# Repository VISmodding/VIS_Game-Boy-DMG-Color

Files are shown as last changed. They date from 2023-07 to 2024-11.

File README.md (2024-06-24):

# Game Boy DMG Color

Original MouseBiteLabs DMGC project can be found [here](https://github.com/MouseBiteLabs/Game-Boy-DMG-Color)

In the DMGC_VIS_variant folder [here](https://github.com/VISmodding/VIS_Game-Boy-DMG-Color/tree/main/DMGC_VIS_variant) you can find the VIS lipo battery variant of the origianl DMGC project.

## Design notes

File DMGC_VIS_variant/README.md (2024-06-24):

## Ensure to download the last version of the production files before production (v.4.0 for rev E and v4.1 for rev A, B, C or D).

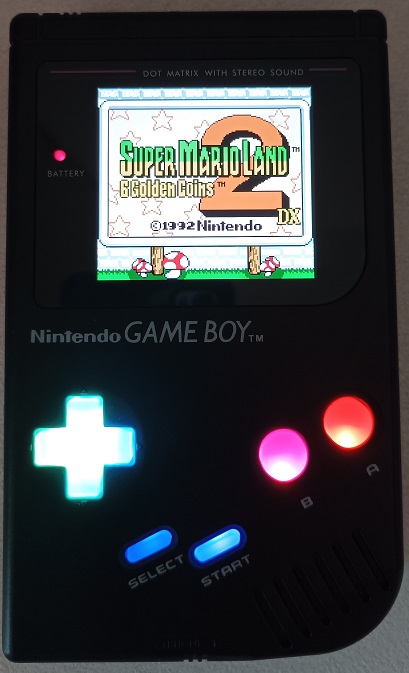
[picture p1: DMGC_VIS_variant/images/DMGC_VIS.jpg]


YouTube video [here](https://www.youtube.com/watch?v=p8AL-SyXEpo&t=13s&ab_channel=V1sModding).
Detailed PCB images can be seen in the production info section [here](PCB_info.md).

This is a modified version of the [MouseBitLab](https://github.com/MouseBiteLabs/Game-Boy-DMG-Color) DMGC project. The changes I have made are the following:
- The power board has been placed on the mainboard (it has a proper ground plane separated from the digital ground plane and from the audio ground plane) and it uses a Lipo battery (clearly it includes also the charger circuit).
- The audio board also has been modified in order to connect the speaker directly on it. For this reason the audio signals are not sent from the mainboard to the front board.
- The DMG donor is not required here (only the link port is needed and it can be sourced directly from the 4-player adapter DMG-07 which is cheap and can source 3 link ports).
- This DMGC VIS variant uses also a different DC jack since we need here of a jack capable to handle 2A current for the charger.
- I provide also the mainboard for the CPU-06 (rev E): the version of the CPU with the RAM already in CPU.

## Disclaimer

**This is a DIY project for electronic enthusiasts. For this reason, I am not responsible for any damage incurred while attempting this project or after completion of the project. You alone accept all risk since you are 100% liable for damage to yourself or your property.**

## Security information for Lipo Battery
The battery is physically distant form the tp4056 linear charger. In addition, the following features are implemented:
- Overcharge and overdischarge protections achieved through the widely used and widespread combo FS8205A - DW01A.
- Load sharing: you can safely play while charging the battery since the battery is disconnected from the load while charging (I use the same circuit of SYF Game Gear since its creator allowed me to use it). 

## Required Donor parts

In this project, the **strictly required donor parts** are only 
  - the **CPU** (that can be sourced from a donor CGB mainboard). For rev E version you need to grab also U11 component from the donor GBC.
  - the **link-port** (that can be sourced from a donor DMG mainboard or from a 4-player adapter DMG-07).

Other **optional components to desolder** from a donor console are:
  - **RAM** chip can be sourced from a donor CGB mainboard or it can be purchased (see BOM file).
  - **Card slot connector and volume wheel** can be sourced from a donor DMG mainboard or can be simply purchased on Aliexpress.
  - **Quartz oscillator** can be sourced from the donor GBC or it can be purchased (see BOM file).
  - **Power switch** can be sourced from a donor DMG mainboard, or a brand new switch can be purchased at any electronic components shop (see BOM file).

## Required Parts to purchase or reuse

  - **All the electronic components** reported in the BOM file.
  - **Housing DMG shell case** (optional if you already have one).
  - **Screen Kit** This is the important one. You need this specific type of kit
      - the Q5 IPS with OSD. It goes by many names, the maker is Hispeedido (*not* FunnyPlaying). Kits that have the screen laminated to a GBC lens are *not* compatible, but kits that include a lit-up logo on the bottom part of the screen are fine to use. Make sure you DO NOT get any Game Boy DMG versions - they are not compatible! Also, be sure to test this screen kit before installing it, preferrably with an original Game Boy Color. Sometimes they arrive damaged, and once you've installed, it may not be possible to get a refund.
      - RGRS: <a href="https://retrogamerepairshop.com/products/game-boy-color-q5-ips-backlight-with-osd?variant=37646279213228">GBC Q5 XL IPS Backlight with OSD</a> OR <a href="https://retrogamerepairshop.com/collections/gbc-displays/products/game-boy-color-q5-osd-ips-kit-with-color-changing-logo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">Game Boy Color Q5 OSD IPS Kit with Color Changing Logo 
      - AliExpress: <a href="https://www.aliexpress.us/item/3256801650459088.html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">GBC Q5 IPS LCD Kit</a>
      - HHL: <a href="https://handheldlegend.com/products/game-boy-color-ips-lcd-q5-hispeedido">Game Boy Color IPS LCD Q5 - Hispeedido</a>
  - **Lens:** You must get the "IPS" style of lens, as the viewing area is larger.
    -	RGRS: <a href="https://retrogamerepairshop.com/collections/dmg-lenses/products/funnyplaying-dmg-q5-ips-lens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">FunnyPlaying DMG Q5 IPS Lens</a>
    - FunnyPlaying: <a href="https://funnyplaying.com/products/dmg-retro-pixel-ips-glass-lens">DMG RetroPixel IPS Glass Lens</a>
  - **Screen Centering Bracket:** In the STL_3D_printer_files you can find:
    -  *dmgc_q5_bracket.stl*: it is the original bucket design (the screen is not covered by the bracket).
    -  *Vis_variant_LCD_bracket.stl*: it is a variant in which the screen is behind the bracket and in this case you need to apply hot glue to keep fix it.
  - **3.7V 125054 Lipo battery** (optional if you want to use only the DC jack).
  - **Kitsch-Bent full silicone buttons** (optional).
  - **1 Watt speaker** (optional if you want to use the original DMG speaker).  You can find (in the files of this project) the 3D model of the holder that you can use to take it in place without glue it to the housing shell (the holder fit the Retrosix 23 mm 1 watt speaker). If you buy 1 watt speaker please buy an high quality speaker from Retrosix (those that I use) or Handheldlegend avoiding cheap speakers.
  - **2 Watt speaker** (optional if you want to use the original DMG speaker). You can buy 28 mm of a very good quality here [Link Aliexpress](https://www.aliexpress.com/item/33037641624.html).
  - **wires and ph2.0 housing connectors** (optional) reported in the last sections of the BOM file.
  - **PH2.0 2.0mm Metal Crimp Pin Terminal Wire Cable for Housing PH 2.0 Female Socket Connector** (optional) that can be purchased here [Link Aliexpress](https://www.aliexpress.com/item/1005004266276874.html).
  - **5v 2A USB-C charger with the 2A cable USB adapter** (I suggest the right angle version) that can be purchased here [Link Aliexpress](https://www.aliexpress.com/item/4000285082506.html).
  - If you decide to use the **audio connector PCB** you can buy the 2.0 mm pitch headers from here [Link Aliexpress](https://www.aliexpress.com/item/4000694199194.html).
  - I suggest to use **full silicone buttons from Kitsch-Bent** as shown in this [short video](https://www.youtube.com/watch?v=DBGJTIemyE4&t=64s&ab_channel=V1sModding).
- I suggest to use **Kamicane USB-C Gasket** to refine the USB-C hole [3D model here](https://www.printables.com/it/model/217706-usb-type-c-gasket).

## Boards compatibility

  - Audio board is not compatible with exisisting gameboy boards and also with my previous Gameboy realeses.
  - MouseBiteLabs front IPS board can be used but in this case lines and ground planes are not kept separated. Anyway, the speaker must be connected in any case to the audio board.

## How produce the PCBs

link [here](PCB_info.md).

## How populate PCBs

Start by populating the power circuit shown in the following image.

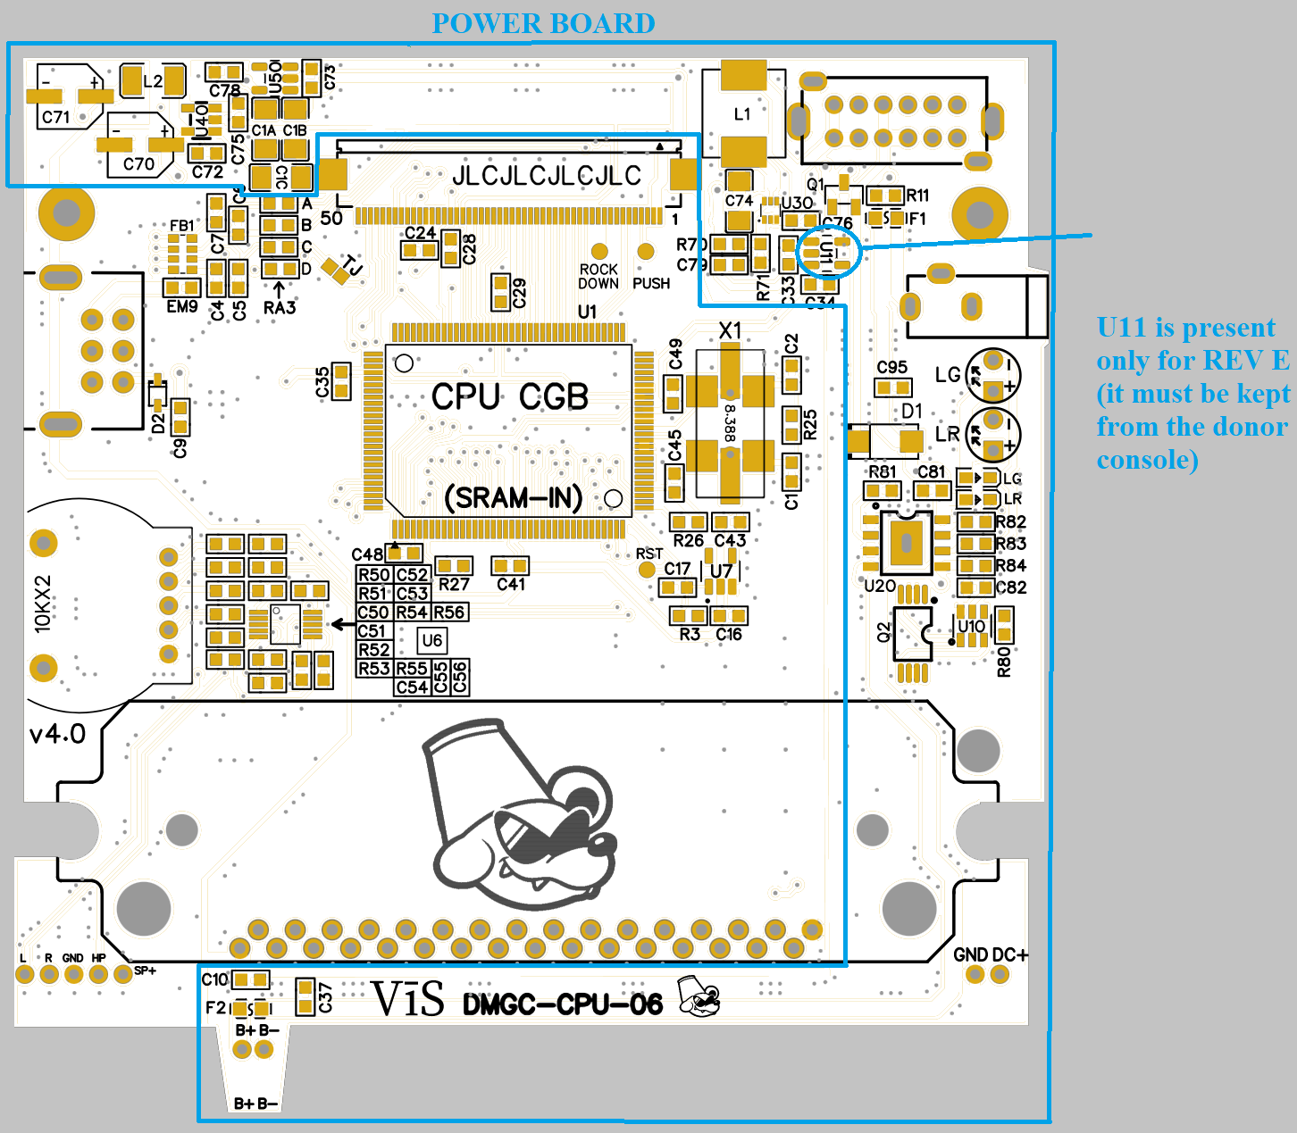
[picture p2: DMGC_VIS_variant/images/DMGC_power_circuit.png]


After that test the voltages on the back by using the pads highlighted in the following image ("Additional CPU lines voltage" pad is present only for the REV E. Here you should get something between 1.8 - 2.5 V) and test also the Lipo charger.

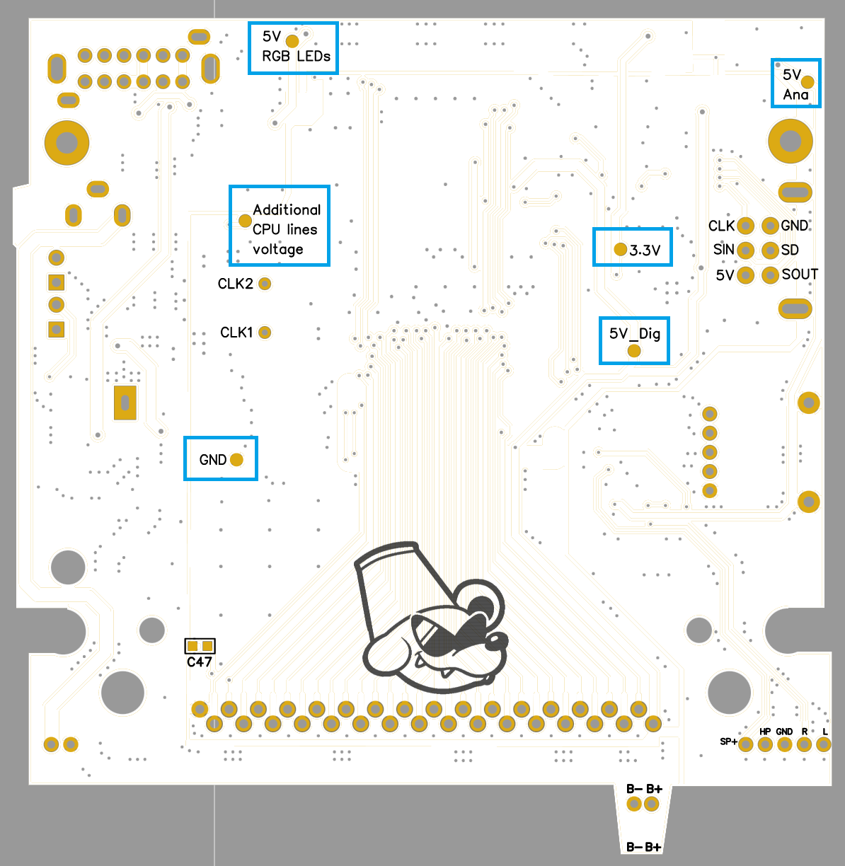
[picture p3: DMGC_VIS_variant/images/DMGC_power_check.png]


At this point you can finish to populate all the PCBs similarly to the MouseBitLabs DMGC. For the audio/USB-C connector please referr to the final part of the DMG v2 video [link](https://www.youtube.com/watch?v=zv3Ng8fEEQI&t=5s&ab_channel=V1sModding).

Finally, all the 7 mm tatcile switches have the same orientation. Referr to the following image for the orientation.

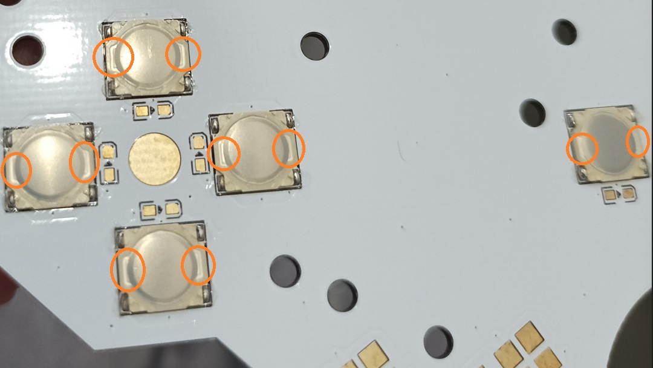
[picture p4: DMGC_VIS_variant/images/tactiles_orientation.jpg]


Other details can be found on the YouTube video [here](https://www.youtube.com/watch?v=p8AL-SyXEpo&t=13s&ab_channel=V1sModding).

## Credits

  - [Bucket Mouse](https://github.com/MouseBiteLabs/) for the [DMGC](https://github.com/MouseBiteLabs/Game-Boy-DMG-Color) project from which I started for this variant.

  - [consolesandcasks or Deceptive thinker](https://github.com/consolesandcasks) for another [Heavy CPU MGB](https://github.com/ConsolesandCasks/CPU-MGB-Heavy) project that I referenced and utilized to update the actual DC Jack.

  - [Kamicane](https://github.com/kamicane/) for the [Super DMG](https://github.com/kamicane/Super-DMG-01) project from wich I get the audio board shape.

  - [Reverse Retro Engineering](https://linktr.ee/reverseretro) for the help in design the rev E CPU.

## Acknowledgements

I would like to thank Mathijs (the creator of SYF Game Gear PCBs) for his several suggestions, schematics, and help in this project. I would like to thank also Luke from Retrosix for some usefull suggestions.

## License
<br />This work is licensed under a <a rel="license" href="http://creativecommons.org/licenses/by-sa/4.0/">Creative Commons Attribution-ShareAlike 4.0 International License</a>. You are able to copy and redistribute the material in any medium or format, as well as remix, transform, or build upon the material for any purpose (even commercial) - but you **must** give appropriate credit, provide a link to the license, and indicate if any changes were made.

## Support VIS projects

I have several stuffs in mind, and I will also share my normal Gameboy DMG work [YouTube Channel](https://www.youtube.com/channel/UC17bQxOnCBejYQG4rzEg3jA), but since developing these things has a high cost in materials and prototypes, a little [PayPal](https://www.paypal.com/donate/?hosted_button_id=RJM3TVFW38ZXL) donation is appreciated.

## Contacts

**email**: vis.modding@gmail.com <br />

**discord**: you can find me as *vis_modding* on several servers (BennVenn, Mouse Bit Lab, Retrosix modding, Game Boy, Gameboy makers, Cybdyn Systems, Pixel FX Official Discord, Modded Gameboy Club).

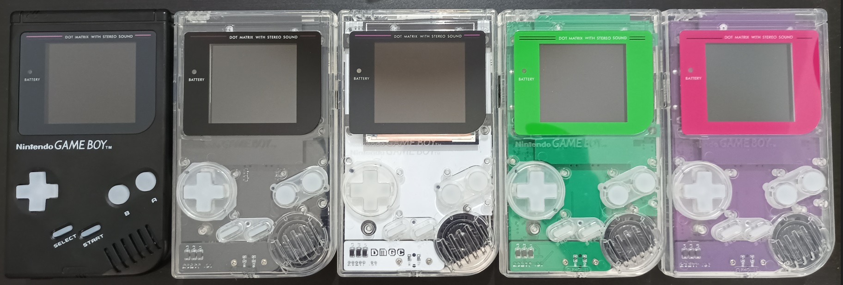
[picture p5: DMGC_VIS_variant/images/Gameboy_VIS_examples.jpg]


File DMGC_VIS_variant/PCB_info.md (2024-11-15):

# Production information

Gerber files are located inside ProductionFiles folder in which you can find 1 PCB in each file.
I suggest ENIG surface finish for easier soldering job and longer PCB shelf life.
Finally, all the PCBs are marked with the string "JLCJLCJLCJLC" in a position that will be covered by components or that will not be visible with the assembled Gameboy. If you order from JLCPCB, you can specify the location of the production file through this string, and they will replace "JLCJLCJLCJLC" with the production number in this location.
If you requires PCBs with a different string (to set the production number in the same location but using another service of production) send me an email and I will provide the modified Gerber files for your needs.
In the following screenshot you find the way to do this.

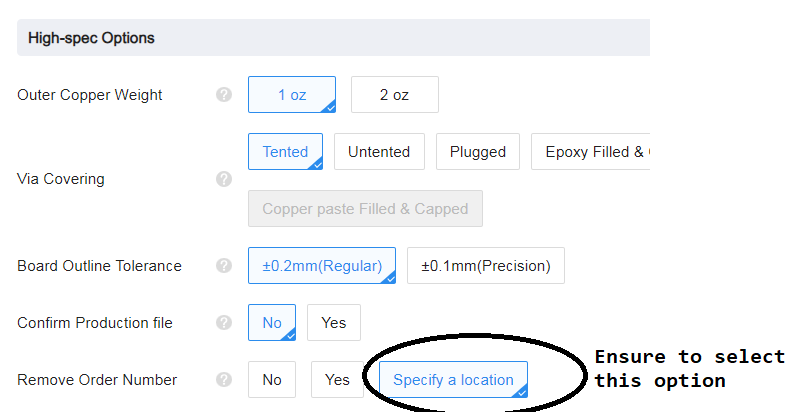
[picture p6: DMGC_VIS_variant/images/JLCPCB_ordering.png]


## Mainboard PCB (2 layers PCB)

Produce the mainboard PCB with 1 mm or 1.2 mm thickness. Here you have the CPU+RAM version or the RAM-IN-CPU (rev E) version.

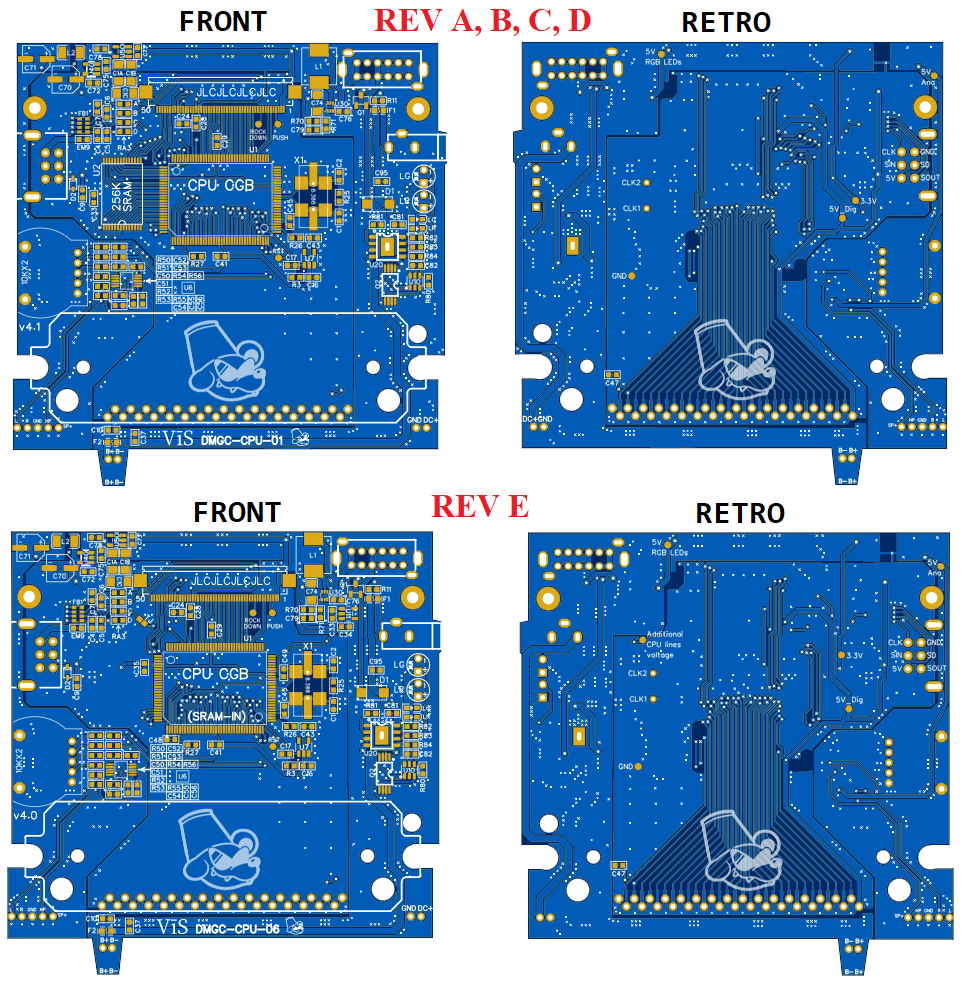
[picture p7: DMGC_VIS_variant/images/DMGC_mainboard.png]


## Audio PCB (2 layers PCB)

Produce the audio PCB with 1 mm or 1.2 mm thickness. 

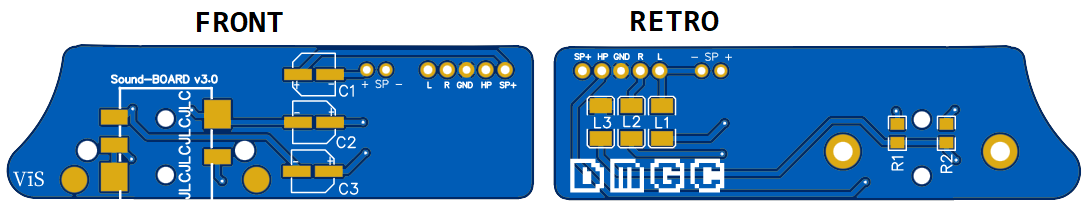
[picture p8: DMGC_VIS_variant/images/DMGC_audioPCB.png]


## Audio Jack raiser (2 layers PCB)

Produce Audio Jack raiser PCB with 1.6 mm thickness. If producer contact you by telling that PCB can break you answer to accept this risk and move on the production.

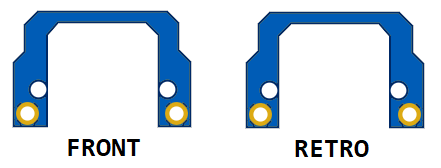
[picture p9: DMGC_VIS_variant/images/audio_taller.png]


## IPS front PCB (2 layers PCB)

Produce the IPS front PCB with 1 mm or 1.2 mm thickness (I suggest ENIG surface finish for better buttons feeling if you don't use tactile buttons). 
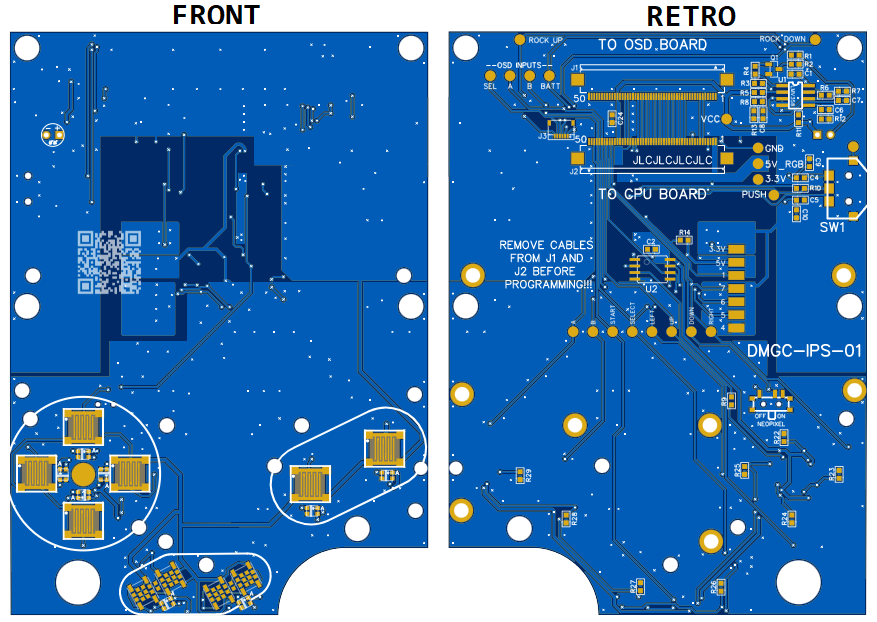
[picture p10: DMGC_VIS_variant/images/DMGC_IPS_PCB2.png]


## Audio connector PCB (2 layers PCB)

Produce the Audio connector PCB with 1 mm or less thickness.

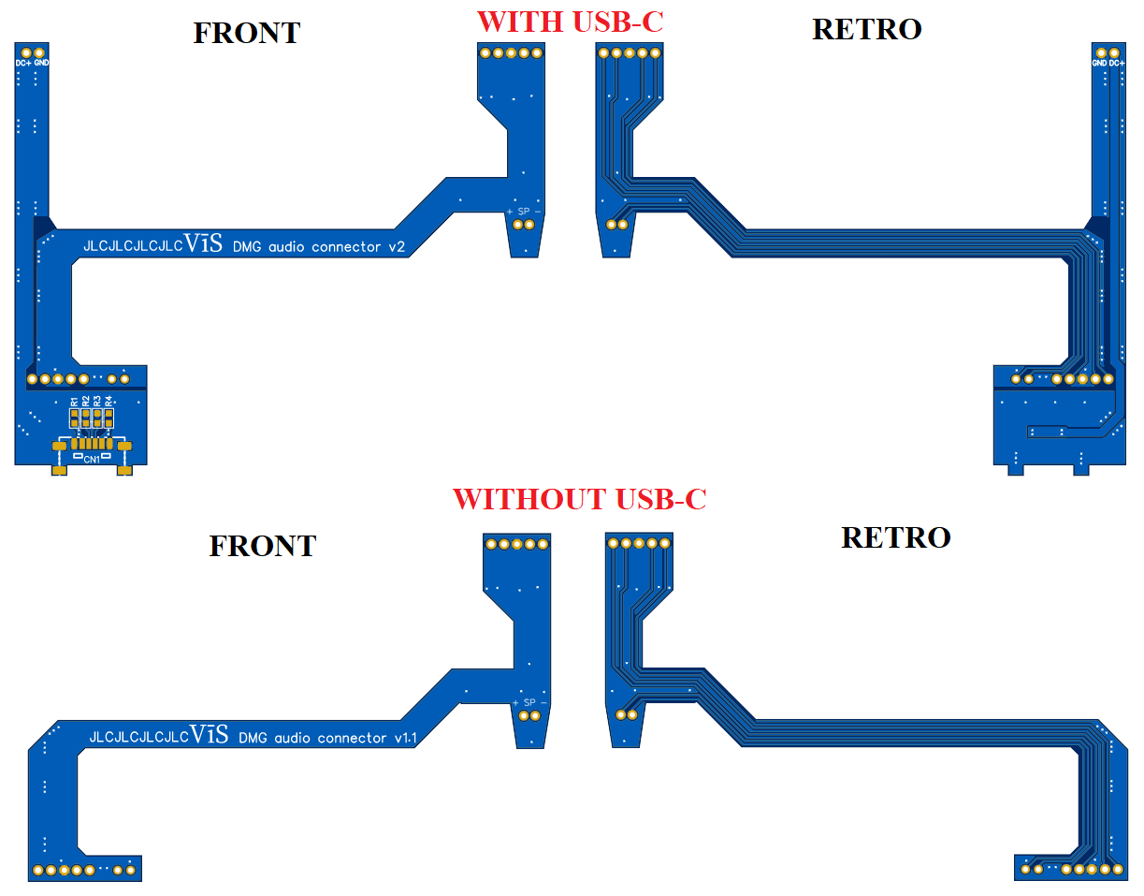
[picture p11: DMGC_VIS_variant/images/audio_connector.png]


## IPS OSD connector PCB (2 layers PCB)

Produce the IPS OSD connector PCB with 0.8 mm or less thickness.

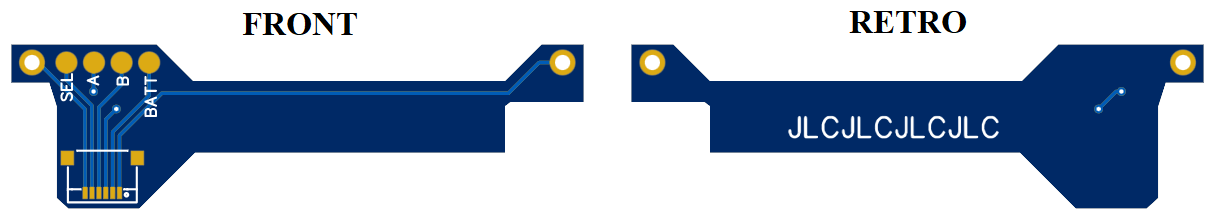
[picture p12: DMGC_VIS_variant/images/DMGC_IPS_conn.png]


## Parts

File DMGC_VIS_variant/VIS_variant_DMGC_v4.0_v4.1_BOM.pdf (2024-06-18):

# VIS GAMEBOY DMGC v4.0_v4.1 BOM

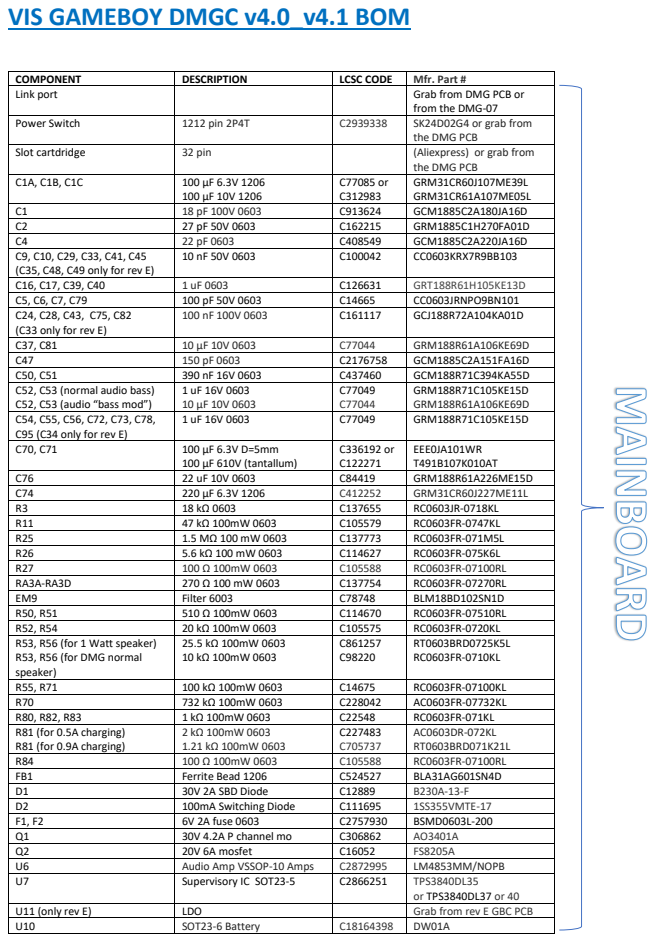
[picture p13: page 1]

COMPONENT | DESCRIPTION | LCSC CODE | Mfr. Part #
Link port | | | Grab from DMG PCB or from the DMG-07

Power Switch | 1212 pin 2P4T | C2939338 | SK24D02G4 or grab from the DMG PCB

Slot cartdridge | 32 pin | | (Aliexpress) or grab from the DMG PCB

C1A, C1B, C1C | 100 μF 6.3V 1206 100 μF 10V 1206 | C77085 or C312983 | GRM31CR60J107ME39L GRM31CR61A107ME05L

C1 | 18 pF 100V 0603 | C913624 | GCM1885C2A180JA16D
C2 | 27 pF 50V 0603 | C162215 | GRM1885C1H270FA01D
C4 | 22 pF 0603 | C408549 | GCM1885C2A220JA16D
C9, C10, C29, C33, C41, C45 (C35, C48, C49 only for rev E) | 10 nF 50V 0603 | C100042 | CC0603KRX7R9BB103

C16, C17, C39, C40 | 1 uF 0603 | C126631 | GRT188R61H105KE13D
C5, C6, C7, C79 | 100 pF 50V 0603 | C14665 | CC0603JRNPO9BN101
C24, C28, C43, C75, C82 (C33 only for rev E) | 100 nF 100V 0603 | C161117 | GCJ188R72A104KA01D

C37, C81 | 10 μF 10V 0603 | C77044 | GRM188R61A106KE69D
C47 | 150 pF 0603 | C2176758 | GCM1885C2A151FA16D
C50, C51 | 390 nF 16V 0603 | C437460 | GCM188R71C394KA55D
C52, C53 (normal audio bass) C52, C53 (audio “bass mod”) | 1 uF 16V 0603 10 μF 10V 0603 | C77049 C77044 | GRM188R71C105KE15D GRM188R61A106KE69D

C54, C55, C56, C72, C73, C78, C95 (C34 only for rev E) | 1 uF 16V 0603 | C77049 | GRM188R71C105KE15D

C70, C71 | 100 μF 6.3V D=5mm 100 μF 610V (tantallum) | C336192 or C122271 | EEE0JA101WR T491B107K010AT

C76 | 22 uF 10V 0603 | C84419 | GRM188R61A226ME15D
C74 | 220 μF 6.3V 1206 | C412252 | GRM31CR60J227ME11L
R3 | 18 kΩ 0603 | C137655 | RC0603JR-0718KL
R11 | 47 kΩ 100mW 0603 | C105579 | RC0603FR-0747KL
R25 | 1.5 MΩ 100 mW 0603 | C137773 | RC0603FR-071M5L
R26 | 5.6 kΩ 100 mW 0603 | C114627 | RC0603FR-075K6L
R27 | 100 Ω 100mW 0603 | C105588 | RC0603FR-07100RL
RA3A-RA3D | 270 Ω 100 mW 0603 | C137754 | RC0603FR-07270RL
EM9 | Filter 6003 | C78748 | BLM18BD102SN1D
R50, R51 | 510 Ω 100mW 0603 | C114670 | RC0603FR-07510RL
R52, R54 | 20 kΩ 100mW 0603 | C105575 | RC0603FR-0720KL
R53, R56 (for 1 Watt speaker) R53, R56 (for DMG normal speaker) | 25.5 kΩ 100mW 0603 10 kΩ 100mW 0603 | C861257 C98220 | RT0603BRD0725K5L RC0603FR-0710KL

R55, R71 | 100 kΩ 100mW 0603 | C14675 | RC0603FR-07100KL
R70 | 732 kΩ 100mW 0603 | C228042 | AC0603FR-07732KL
R80, R82, R83 | 1 kΩ 100mW 0603 | C22548 | RC0603FR-071KL
R81 (for 0.5A charging) R81 (for 0.9A charging) | 2 kΩ 100mW 0603 1.21 kΩ 100mW 0603 | C227483 C705737 | AC0603DR-072KL RT0603BRD071K21L

R84 | 100 Ω 100mW 0603 | C105588 | RC0603FR-07100RL
FB1 | Ferrite Bead 1206 | C524527 | BLA31AG601SN4D
D1 | 30V 2A SBD Diode | C12889 | B230A-13-F
D2 | 100mA Switching Diode | C111695 | 1SS355VMTE-17
F1, F2 | 6V 2A fuse 0603 | C2757930 | BSMD0603L-200
Q1 | 30V 4.2A P channel mo | C306862 | AO3401A
Q2 | 20V 6A mosfet | C16052 | FS8205A
U6 | Audio Amp VSSOP-10 Amps | C2872995 | LM4853MM/NOPB
U7 | Supervisory IC SOT23-5 | C2866251 | TPS3840DL35 or TPS3840DL37 or 40

U11 (only rev E) | LDO | | Grab from rev E GBC PCB
U10 | SOT23-6 Battery | C18164398 | DW01A

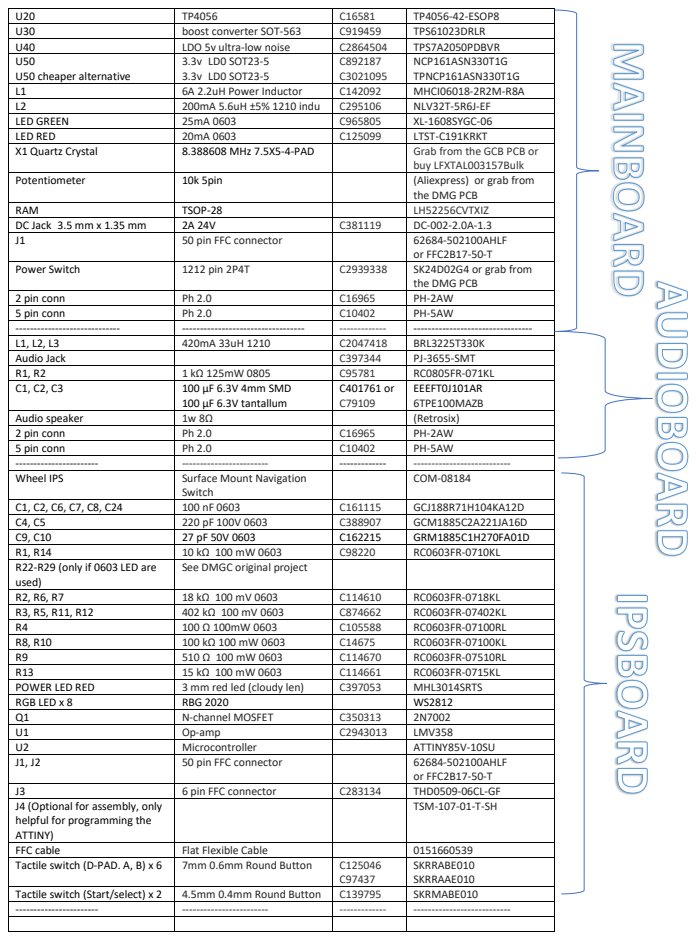
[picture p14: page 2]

U20 | TP4056 | C16581 | TP4056 -42 -ESOP8
U30 | boost converter SOT -563 | C919459 | TPS61023DRLR
U4 0 | LDO 5v ultra -low noise | C2864504 | TPS7A2050PDBVR
U50 U50 cheaper alternative | 3.3v LD0 SOT23 -5 | C892187 C3021095 | NCP161ASN330T1G TPNCP161ASN330T1G

L1 | 6A 2.2uH Power Inductor | C142092 | MHCI06018 -2R2M -R8A
L2 | 200mA 5.6uH ±5% 1210 indu | C295106 | NLV32T -5R6J -EF
LED GREEN | 25mA 0603 | C965805 | XL -1608SYGC -06
LED RED | 20mA 0603 | C125099 | LTST -C191KRKT
X1 Quartz Crystal | 8.388608 MHz 7.5X5 -4 -PAD | | Grab from the GCB PCB or buy LFXTAL003157Bulk

Potentiometer | 10k 5pin | | (Aliexpress) or grab from the DMG PCB

RAM | TSOP -28 | | LH52256CVTXIZ
DC Jack 3.5 mm x 1.35 mm | 2A 24V | C381119 | DC -002 -2.0A -1.3
J1 | 50 pin FFC connector | | 62684 -502100AHLF or FFC2B17 -50 -T

Power Switch | 1212 pin 2P4T | C2939338 | SK24D02G4 or grab from the DMG PCB

2 pin conn | Ph 2.0 | C16965 | PH -2AW
5 pin conn | Ph 2.0 | C10402 | PH -5AW
----------------------------- | ---------------------------------- | ------------- | ---------------------------------
L1, L2, L3 | 420mA 33uH 1210 | C2047418 | BRL3225T330K
Audio Jack | | C397344 | PJ -3655 -SMT
R 1, R 2 | 1 kΩ 125mW 0805 | C95781 | RC0805FR -071KL
C 1, C 2, C 3 | 100 μF 6.3V 4mm SMD 100 μF 6.3V tantallum | C401761 or C79109 | EEEFT0J101AR 6TPE100MAZB

Audio speaker | 1w 8Ω | | (Retrosix )
----------------------- | ------------------------ | ------------- | ---------------------------
Wheel IPS | Surface Mount Navigation Switch | | COM -08184

C1, C2, C6, C7, C8, C24 | 100 nF 0603 | C161115 | GCJ188R71H104KA12D
C4, C5 | 220 pF 100V 0603 | C388907 | GCM1885C2A221JA16D
C9, C10 | 27 pF 50V 0603 | C162215 | GRM1885C1H270FA01D
R1, R14 | 10 kΩ 100 mW 0603 | C98220 | RC0603FR -0710KL
R22 -R29 (only if 0603 LED are used) | See DMGC original project

R2, R6, R7 | 18 kΩ 100 mV 0603 | C114610 | RC0603FR -0718KL
R3, R5, R11, R12 | 402 kΩ 100 mV 0603 | C874662 | RC0603FR -07402KL
R4 | 100 Ω 100mW 0603 | C105588 | RC0603FR -07100RL
R8, R10 | 100 kΩ 100 mW 0603 | C14675 | RC0603FR -07100KL
R9 | 510 Ω 100 mW 0603 | C114670 | RC0603FR -07510RL
R13 | 15 kΩ 100 mW 0603 | C114661 | RC0603FR -0715KL
POWER LED RED | 3 mm red led (cloudy len) | C397053 | MHL3014SRTS
RGB LED x 8 | RBG 2020 | | WS2812
Q1 | N -channel MOSFET | C350313 | 2N7002
U1 | Op -amp | C2943013 | LMV358
U2 | Microcontroller | | ATTINY85V -10SU
J1, J2 | 50 pin FFC connector | | 62684 -502100AHLF or FFC2B17 -50 -T

J3 | 6 pin FFC connector | C283134 | THD0509 -06CL -GF
J 4 (Optional for assembly, only helpful for programming the ATTINY) | | | TSM -107 -01 -T -SH

FFC cable | Flat Flexible Cable | | 0151660539
Tactile switch (D -PAD. A, B) x 6 | 7mm 0.6mm Round Button | C125046 C97437 | SKRRABE010 SKRRAAE010

Tactile switch (Start/select) x 2 | 4.5mm 0. 4mm Round Button | C139795 | SKRMABE010

## Audio connector

# OSD connector

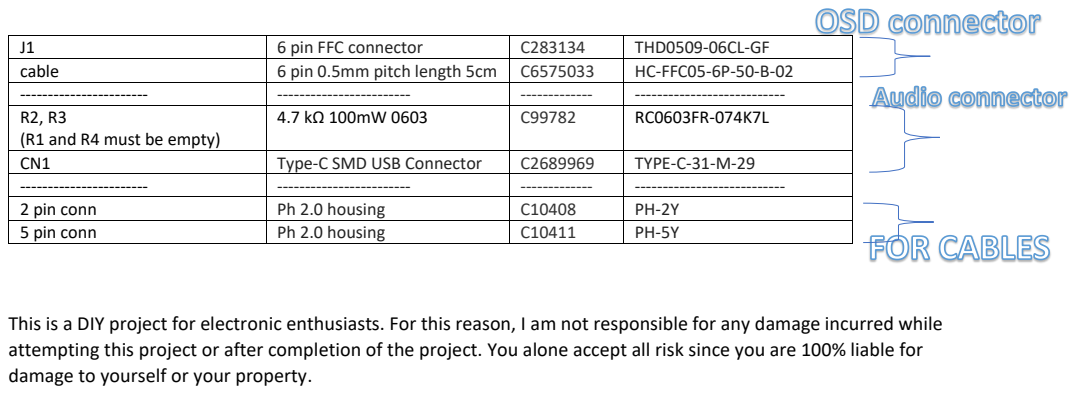
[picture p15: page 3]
FOR CABLES

J1 | 6 pin FFC connector | C283134 | THD0509-06CL-GF
cable | 6 pin 0.5mm pitch length 5cm | C6575033 | HC-FFC05-6P-50-B-02
----------------------- | ------------------------ | ------------- | ---------------------------
R2, R3 (R1 and R4 must be empty) | 4.7 kΩ 100mW 0603 | C99782 | RC0603FR-074K7L

CN1 | Type-C SMD USB Connector | C2689969 | TYPE-C-31-M-29
2 pin conn | Ph 2.0 housing | C10408 | PH-2Y
5 pin conn | Ph 2.0 housing | C10411 | PH-5Y

This is a DIY project for electronic enthusiasts. For this reason, I am not responsible for any damage incurred while
attempting this project or after completion of the project. You alone accept all risk since you are 100% liable for
damage to yourself or your property.

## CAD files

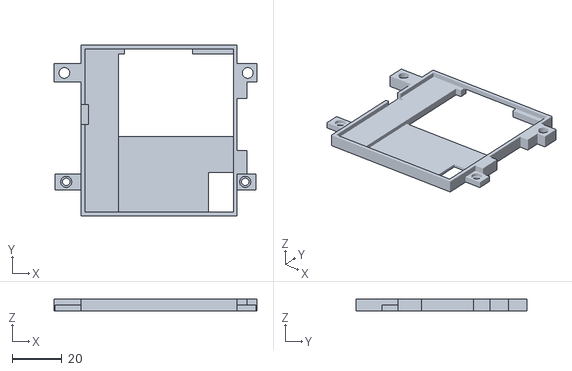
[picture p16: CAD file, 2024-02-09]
DMGC_VIS_variant/STL_3D_printer_files/dmgc_q5_bracket.stl
82.0 x 69.0 x 5.00

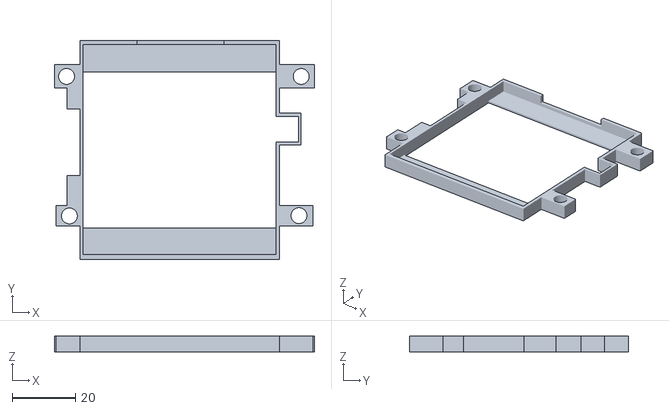
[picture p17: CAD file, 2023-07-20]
DMGC_VIS_variant/STL_3D_printer_files/Vis_variant_LCD_bracket.stl
82.0 x 69.0 x 5.00

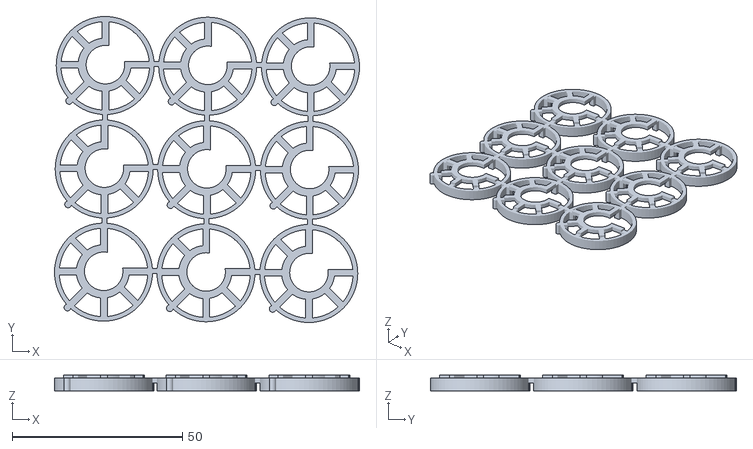
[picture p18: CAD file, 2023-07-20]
DMGC_VIS_variant/STL_3D_printer_files/array_speaker_holder_v2.stl
89.6 x 89.9 x 4.60
